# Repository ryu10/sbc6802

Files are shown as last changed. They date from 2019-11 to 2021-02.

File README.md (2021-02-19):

# SBC6802 plus Bus

[Ja](READMEj.md) | En

Rev. 2

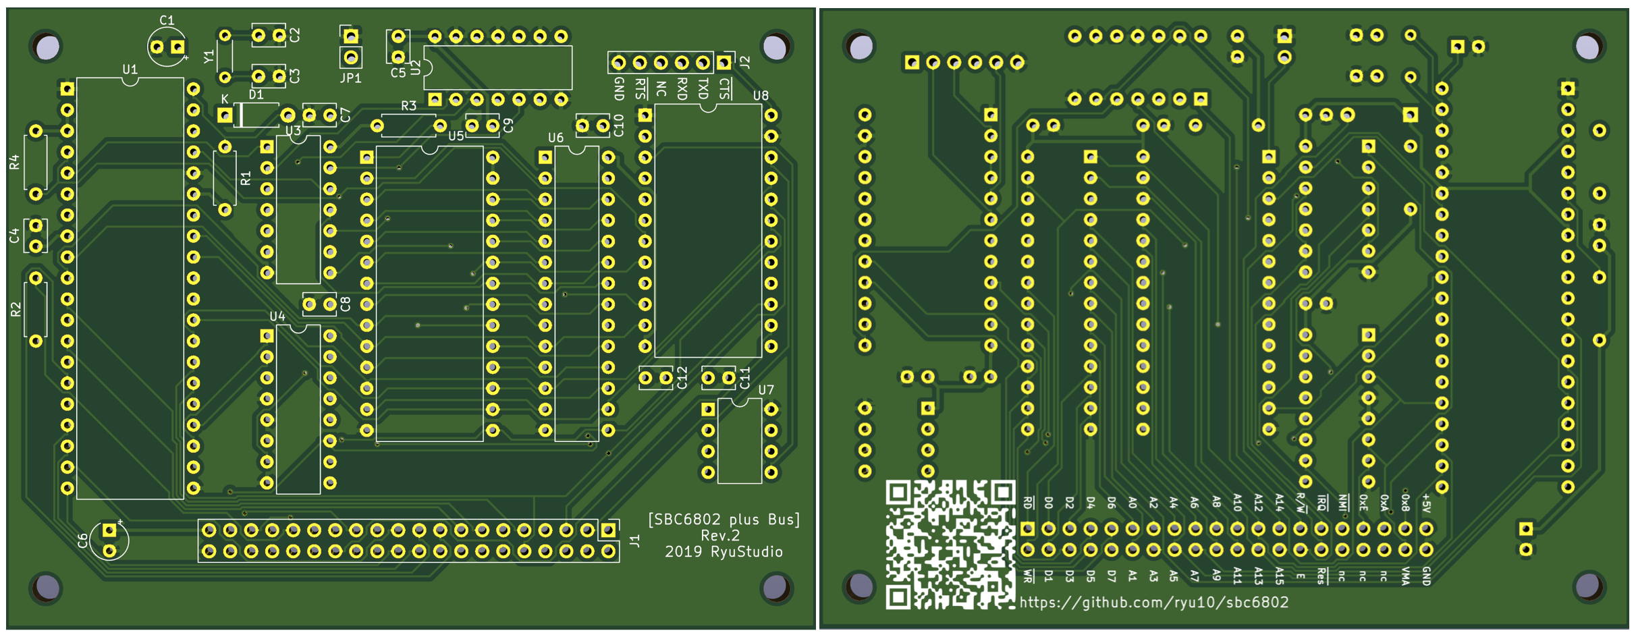
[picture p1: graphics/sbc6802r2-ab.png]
boardr2


An MC6802-based single board computer. The board design is derived from SBC6800 and SBC6809.

## Features

* MC6802 1MHz
* RAM 32KB (0x0000 - 0x7fff)
* ROM 16KB (0xc000 - 0xffff x two banks, selectable using JP1)
* ACIA (0x8018/0x8019)
* SBC-Bus 2.0 Connector

## In This Repository

The following files are included, along with the KiCAD project:

* [Schematic](sbc6802_r2_sch.pdf)
* [Gerber](sbc6802_gerber_r2.zip)
* [BOM](sbc6802_r2_BOM.pdf)

## Programming PIC12F1822

PIC12F1822（U7）can be programmed with ```osc1536.hex``` found in [SBC6800 datapack](http://www.amy.hi-ho.ne.jp/officetetsu/storage/sbc6800_datapack.zip) to generate the clock for 6850 ACIA. The serial port will operate at 9600 bps.
## SBC-Bus

The bus connector J1 supports [SBC-Bus 2.0](https://store.shopping.yahoo.co.jp/orangepicoshop/pico-a-008.html). Pin 38 is routed to 6802 VMA.

If the board is not connected to the SBC-Bus, connect the 5V and GND pins to a +5V regulated power supply.

## Software

Most of the 6800 software found in [SBC6800 datapack](http://www.amy.hi-ho.ne.jp/officetetsu/storage/sbc6800_datapack.zip) are compatible with SBC6802.

## References

* [SBC6800](https://www.switch-science.com/catalog/3581/) / [Technical Data PDF](http://www.amy.hi-ho.ne.jp/officetetsu/storage/en/sbc6800_techdata.pdf)
* [SBC6809](https://www.switch-science.com/catalog/3583/)
* [SBC-Bus 2.0](https://store.shopping.yahoo.co.jp/orangepicoshop/pico-a-008.html)
* [as0 Motorola 6800 Assembler](https://github.com/JimInCA/motorola-6800-assembler)
* [M6800 Assembly VSCode Extension](https://marketplace.visualstudio.com/items?itemName=RyuStudio.m6800-as0)

## License

CC-BY-SA 3.0
2019 ryu10/RyuStudio.

Derived from the original works of SBC6800 and SBC6809 (c) 2017-2018 Tetsuya Suzuki.

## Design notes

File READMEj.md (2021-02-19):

# SBC6802 plus Bus

Ja | [En](README.md)

Rev. 2

boardr2

モトローラ MC68B02 を使用したシングルボードコンピュータです。SBC6800/SBC6809（@vintagechips 様設計）からの派生です。SBC-Bus 2.0（@tomi9tw 様設計）対応のコネクタを装備しています。

## 搭載機能

本ボードの機能は以下の通りです。

* MPU MC6802 1MHz（内蔵 RAM 無効）
* RAM 32KB（0x0000 - 0x7fff）
* ROM 16KB（0xc000 - 0xffff x 2 バンク、ジャンパ JP1 で選択）
* ACIA MC6850（0x8018/0x8019）
* SBC-Bus 2.0 コネクタ

## 主なファイル

リポジトリに含まれる主要なファイルは次の通りです。

* [回路図](sbc6802_r2_sch.pdf)
* [Gerber](sbc6802_gerber_r2.zip)
* [部品表](sbc6802_r2_BOM.pdf)

これ以外に、KiCAD プロジェクトのディレクトリが含まれます。

## PIC12F1822 のプログラミング

PIC12F1822（U7）は 6850 ACIA へシリアルクロックを供給します。[SBC6800 データパック](http://www.amy.hi-ho.ne.jp/officetetsu/storage/sbc6800_datapack.zip)に含まれる osc1536.hex を利用してプログラムすると 9600 bps シリアル通信が可能になります。
## SBC-Bus

SBC-Bus 2.0 の標準ピンアサインから 1 か所変更があります。

* Pin 38: VMA（標準アサインでは NC）

ご利用の SBC-Bus ピンアサインと競合する場合は、基板はんだ面の 38 ピン付近でパターンカットしてください。

SBC6802 plus Bus ボードの電源とリセットボタンは SBC-Bus に依存します。SBC-Bus へ接続しない場合は、ボード下部のコネクタ端子から +5V、GND、Res*（リセット）などを取り出して配線してください。端子名は基板はんだ面のシルクに印刷されています。

## SBC6800 用ソフトウェア

SBC6802 plus Bus のメモリおよび ACIA アドレスは SBC6800 互換です。[SBC6800 データパック](http://www.amy.hi-ho.ne.jp/officetetsu/storage/sbc6800_datapack.zip)に含まれる Mikbug と VTLSA の動作を確認しています。未検証ですがデータパック内の他のソフトウェアも使用可能だと思います。

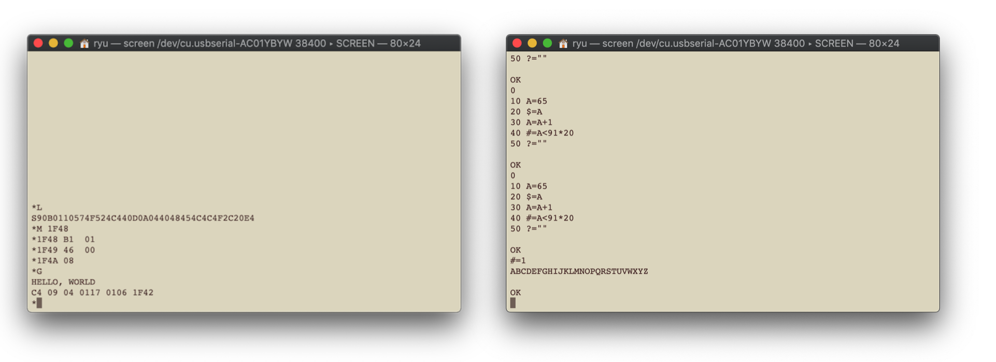
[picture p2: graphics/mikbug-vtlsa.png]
mikbug-vtlsa


## 参考リンク

* [SBC6800](https://www.switch-science.com/catalog/3581/)
* [SBC6809](https://www.switch-science.com/catalog/3583/)
* [SBC-Bus 2.0](https://store.shopping.yahoo.co.jp/orangepicoshop/pico-a-008.html)
* [as0 Motorola 6800 Assembler](https://github.com/JimInCA/motorola-6800-assembler)
* [M6800 Assembly VSCode Extension](https://marketplace.visualstudio.com/items?itemName=RyuStudio.m6800-as0)

## ライセンス

CC-BY-SA 3.0 
2019 ryu10/RyuStudio. 本制作物は以下の設計からの派生です。

SBC6800 and SBC6809, (c) 2017-2018 Tetsuya Suzuki.

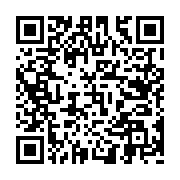
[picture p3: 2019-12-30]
github_sbc6802r2.png

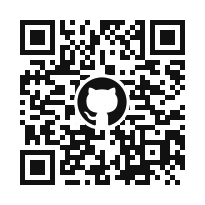
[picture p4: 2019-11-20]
github_sbc6802.png

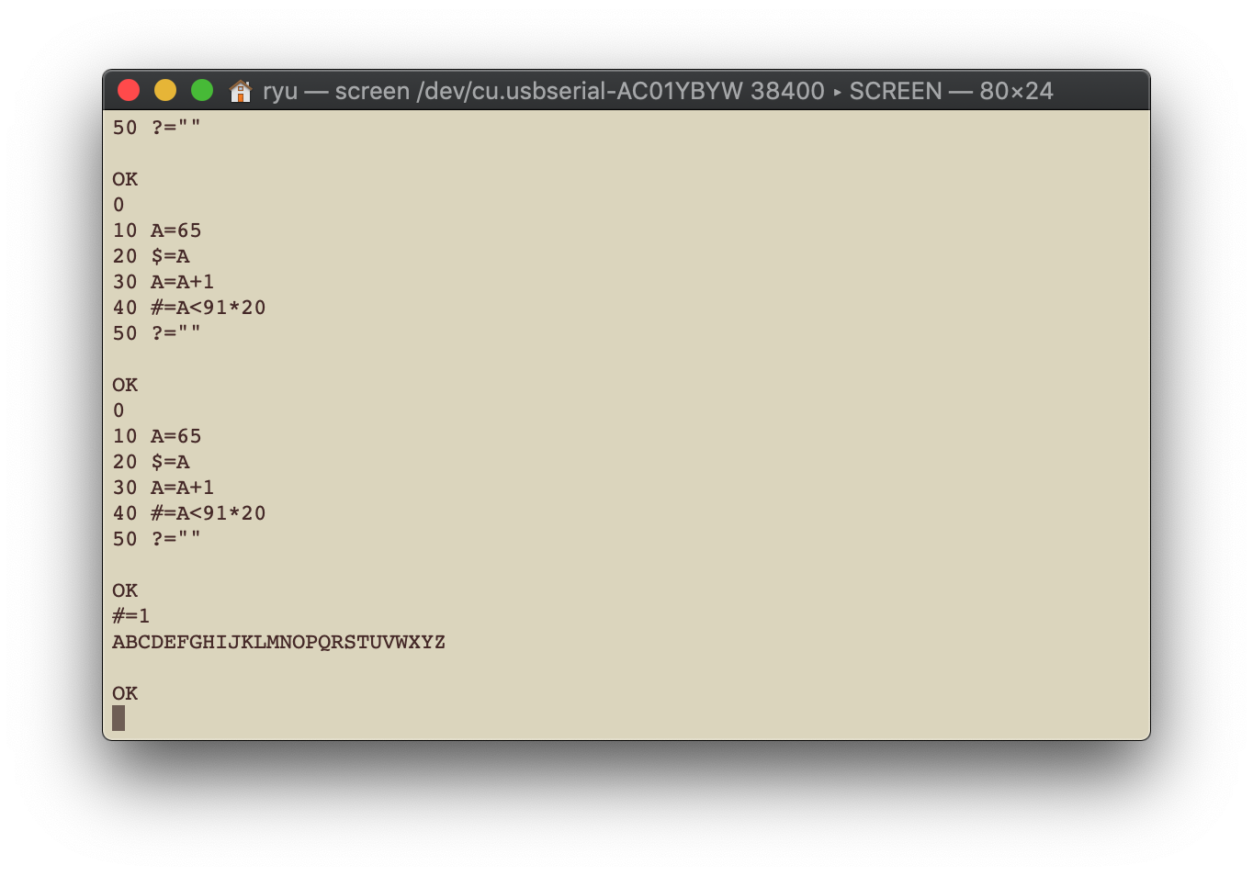
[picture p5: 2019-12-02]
graphics/vtlsa.png

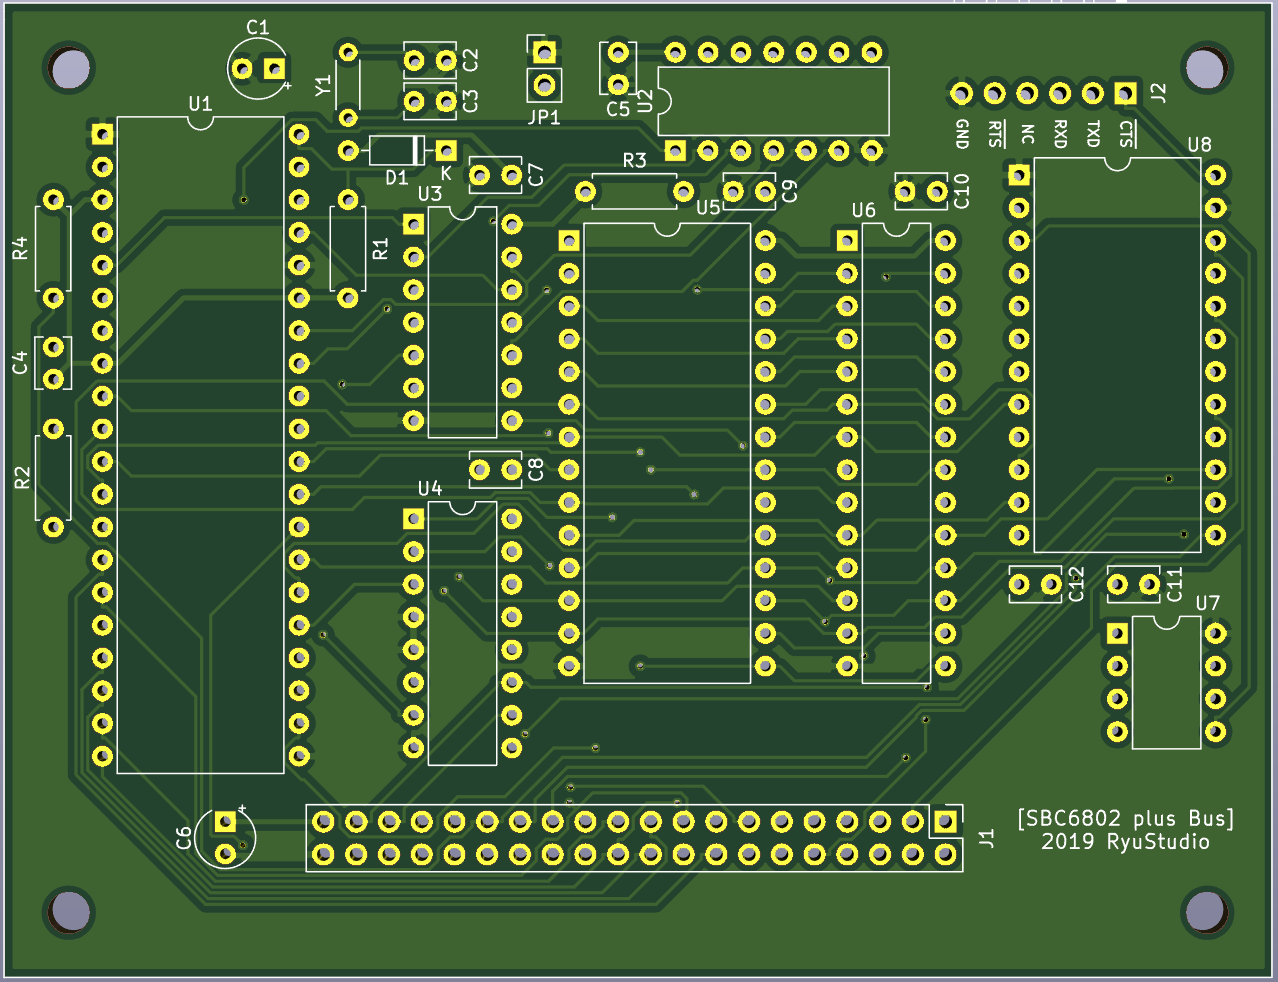
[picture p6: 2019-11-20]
KiCAD/graphics/sbc6802board1a.png

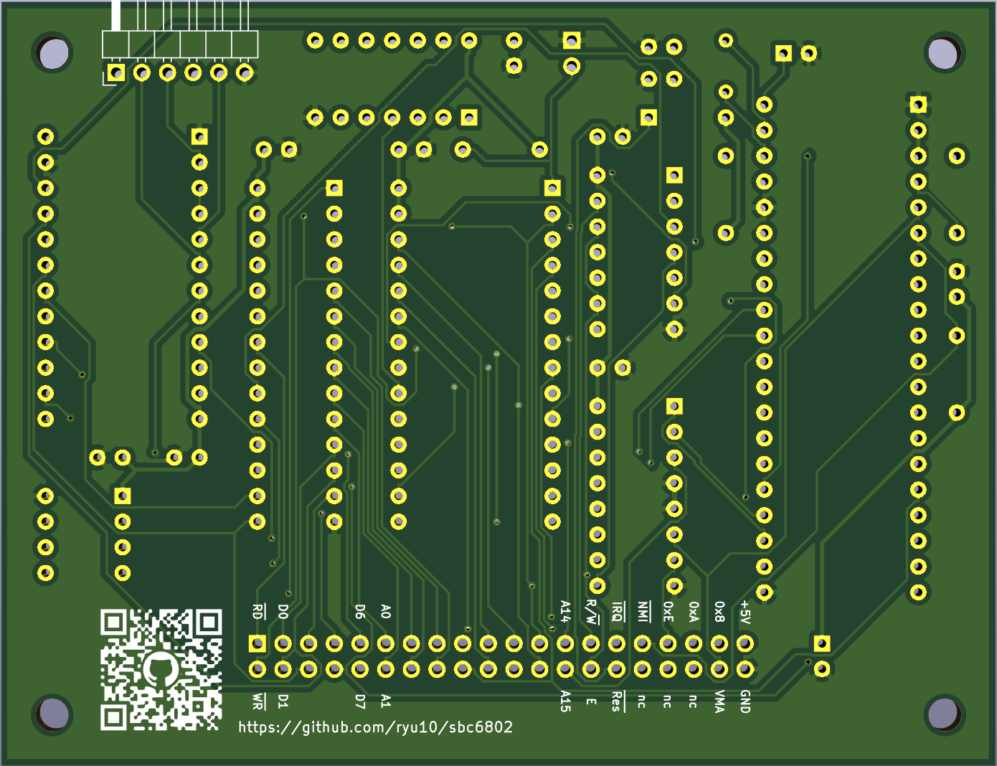
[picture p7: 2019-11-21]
KiCAD/graphics/sbc6802board2a.png

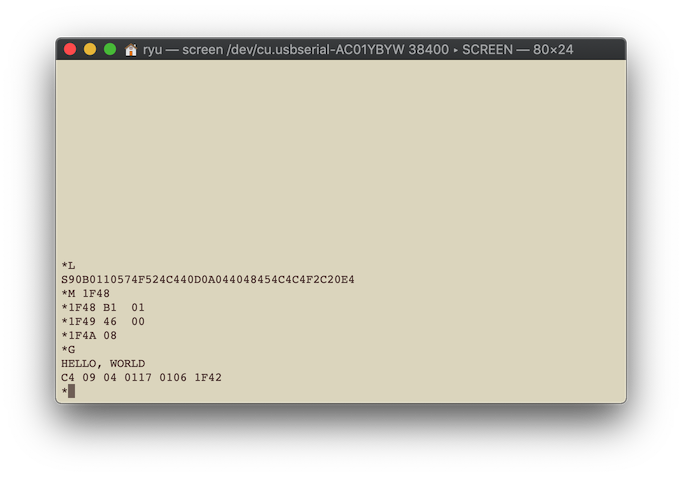
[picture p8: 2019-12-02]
graphics/mikbughello.png

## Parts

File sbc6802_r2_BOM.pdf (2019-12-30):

sbc6802_rev2_BOM

Designator | Package | Quantity | Designation | Supplier and ref
C1 | CP_Radial_Tantal_D4.5mm_P2.50mm | 1 | 10u | electrolytic cap
C11,C10,C12,C4,C5,C7,C8,C9 | C_Disc_D3.8mm_W2.6mm_P2.50mm | 8 | 0.1u | ceramic cap
C2,C3 | C_Disc_D3.8mm_W2.6mm_P2.50mm | 2 | 22p | ceramic cap
C6 | CP_Radial_Tantal_D4.5mm_P2.50mm | 1 | 100u | electrolytic cap
D1 | D_A-405_P7.62mm_Horizontal | 1 | DIODE | diode
G1 | qr_github_sbc6802_r2 | 1 | LOGO | (no parts)
J1 | PinHeader_2x20_P2.54mm_Vertical | 1 | SBC_Bus | https://store.shopping.yahoo.co.jp/soten2/a14061000ux0357.html?sc_i=shp_pc_search_itemlist_shsrg_title
J2 | PinHeader_1x06_P2.54mm_Horizontal | 1 | Conn_01x06 | pin hdr
JP1 | PinHeader_1x02_P2.54mm_Vertical | 1 | Jumper_NO_Small | pin hdr
mh4,mh3,mh2,mh1 | MountingHole_3.2mm_M3 | 4 | M3 | (no parts)
R1 | R_Axial_DIN0207_L6.3mm_D2.5mm_P7.62mm_Horizontal | 1 | 47k | R axial
R2,R3,R4 | R_Axial_DIN0207_L6.3mm_D2.5mm_P7.62mm_Horizontal | 3 | 4.7k | R axial
U1 | DIP-40_W15.24mm | 1 | MC6802 + dip socket | IC
U2 | DIP-14_W7.62mm | 1 | 74LS04 + dip socket | IC
U3 | DIP-14_W7.62mm | 1 | 74LS00 + dip socket | IC
U4 | DIP-16_W7.62mm | 1 | 74LS138 + dip socket | IC
U5 | DIP-28_W15.24mm | 1 | AT28C256 EEPROM + dip socket | https://www.digikey.com/product-detail/en/microchip-technology/AT28C256-15PU/AT28C256-15PU-ND/1008506
U6 | DIP-28_W7.62mm | 1 | 71256 32KB SRAM (w7.62mm) + dip socket
U7 | DIP-8_W7.62mm | 1 | PIC12F1822-IP + dip socket | IC
U8 | DIP-24_W15.24mm | 1 | MC6850 + dip socket | IC
Y1 | R_Axial_DIN0204_L3.6mm_D1.6mm_P5.08mm_Horizontal | 1 | 4MHz | crystal

https://www.digikey.com/product-detail/en/idt-integrated-device-technology-inc/71256SA12TPG/800-3674-ND/2011023

1

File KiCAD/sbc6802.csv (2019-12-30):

Id | Designator | Package | Quantity | Designation | Supplier and ref
1 | logo1 | qr_github_sbc6802_r2 | 1 | LOGO
2 | mh4,mh3,mh2,mh1 | MountingHole_3.2mm_M3 | 4 | M3
3 | J2 | PinHeader_1x06_P2.54mm_Vertical | 1 | Conn_01x06
4 | C1 | CP_Radial_Tantal_D4.5mm_P2.50mm | 1 | 10u
5 | C2,C3 | C_Disc_D3.8mm_W2.6mm_P2.50mm | 2 | 22p
6 | JP1 | PinHeader_1x02_P2.54mm_Vertical | 1 | Jumper_NO_Small
7 | R1 | R_Axial_DIN0207_L6.3mm_D2.5mm_P7.62mm_Horizontal | 1 | 47k
8 | R2,R3,R4 | R_Axial_DIN0207_L6.3mm_D2.5mm_P7.62mm_Horizontal | 3 | 4.7k
9 | J1 | PinHeader_2x20_P2.54mm_Vertical | 1 | Conn_02x20_Odd_Even
10 | U1 | DIP-40_W15.24mm | 1 | MC6802
11 | U2 | DIP-14_W7.62mm | 1 | 74LS04
12 | U3 | DIP-14_W7.62mm | 1 | 74LS00
13 | U4 | DIP-16_W7.62mm | 1 | 74LS138
14 | U5 | DIP-28_W15.24mm | 1 | 28C256 EEPROM
15 | U6 | DIP-28_W7.62mm | 1 | 71256 32KB SRAM
16 | U7 | DIP-8_W7.62mm | 1 | PIC12F1822-IP
17 | U8 | DIP-24_W15.24mm | 1 | MC6850
18 | Y1 | R_Axial_DIN0204_L3.6mm_D1.6mm_P5.08mm_Horizontal | 1 | 4MHz
19 | C11,C10,C12,C4,C5,C7,C8,C9 | C_Disc_D3.8mm_W2.6mm_P2.50mm | 8 | 0.1u
20 | C6 | CP_Radial_Tantal_D4.5mm_P2.50mm | 1 | 100u
21 | D1 | D_A-405_P7.62mm_Horizontal | 1 | D

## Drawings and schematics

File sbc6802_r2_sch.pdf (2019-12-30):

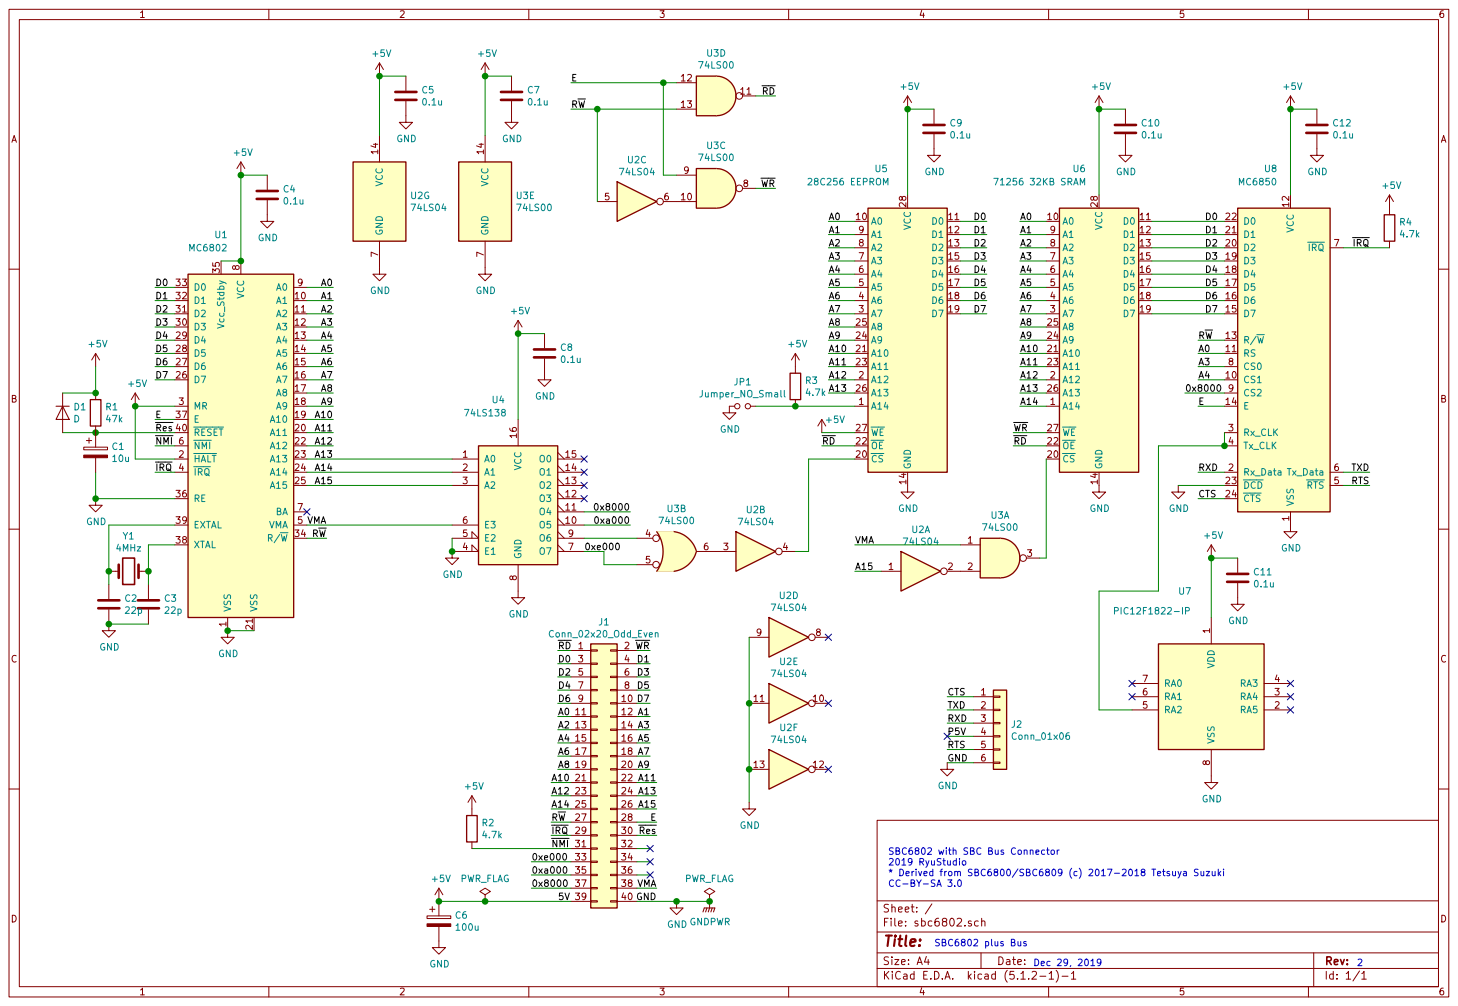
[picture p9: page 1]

1 A1 10 A2 11 A3 12 A4 13 A5 14 A6 15 A7 16 A8 17 A9 18 A10 19 HALT 2 A11 20 VSS 21 A12 22 A13 23 A14 24 A15 25 D7 26 D6 27 D5 28 D4 29 MR 3 D3 30 D2 31 D1 32 D0 33 R/W 34 Vcc_Stdby 35 RE 36 E

Id: 1/1 Title: File: sbc6802.sch Sheet: / SBC6802 plus Bus VSS

* Derived from SBC6800/SBC6809 (c) 2017-2018 Tetsuya Suzuki CC-BY-SA 3.0

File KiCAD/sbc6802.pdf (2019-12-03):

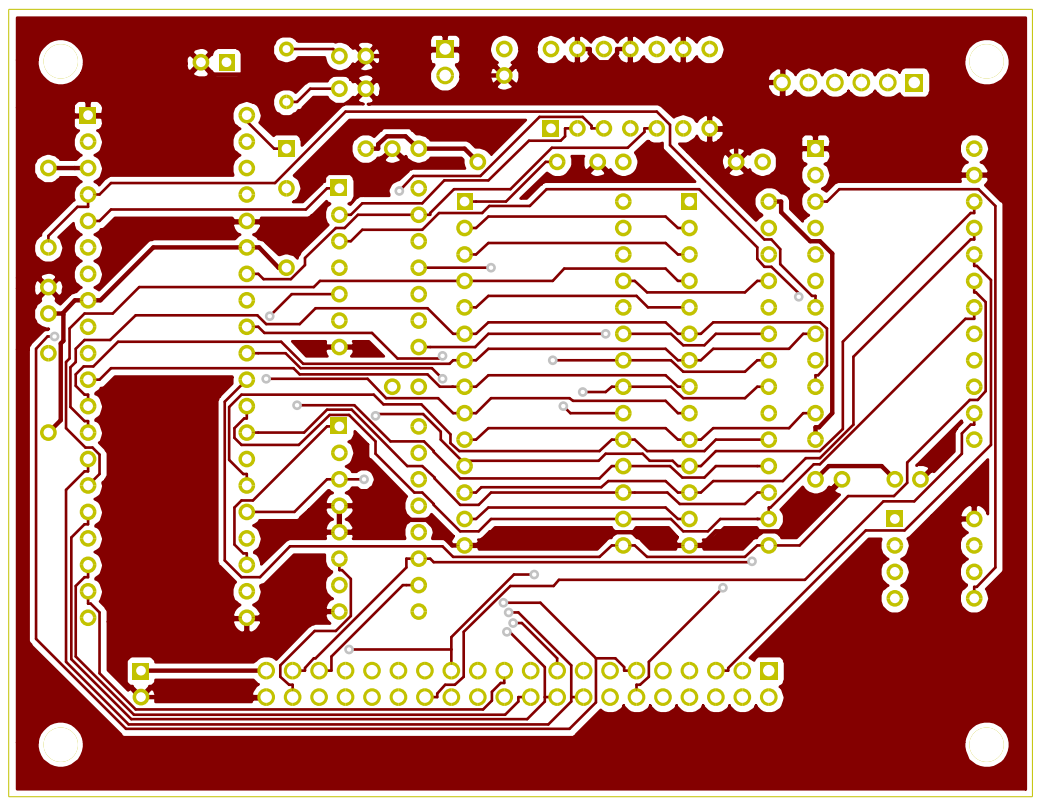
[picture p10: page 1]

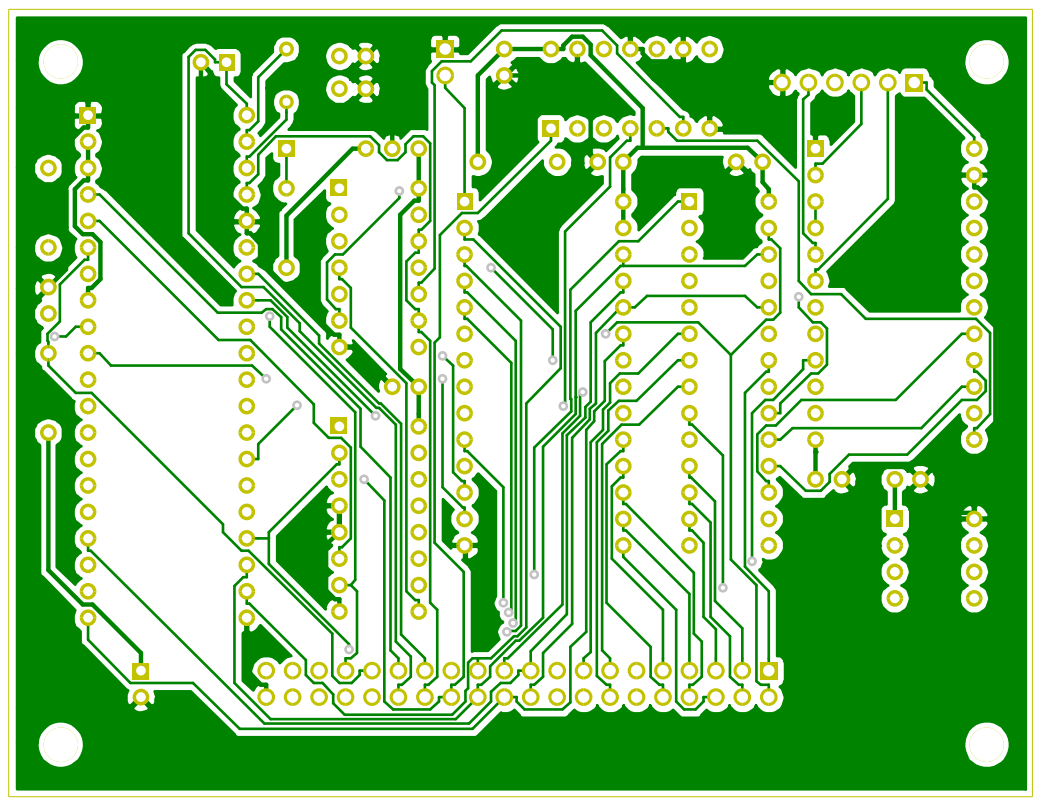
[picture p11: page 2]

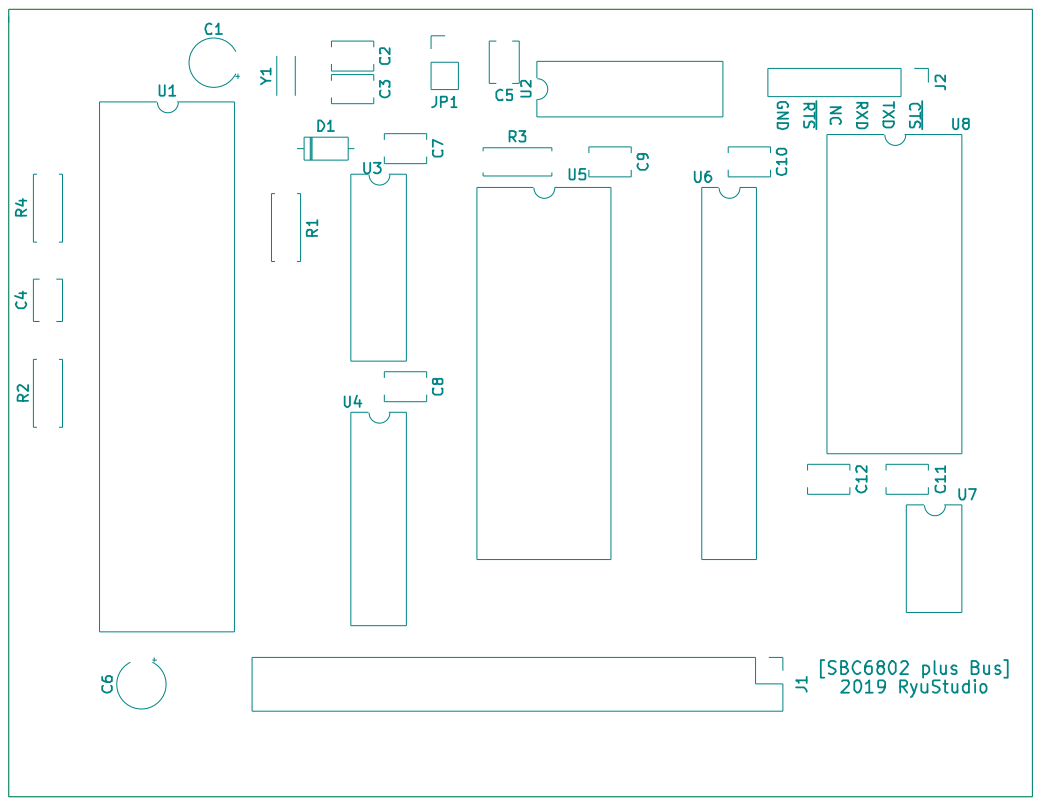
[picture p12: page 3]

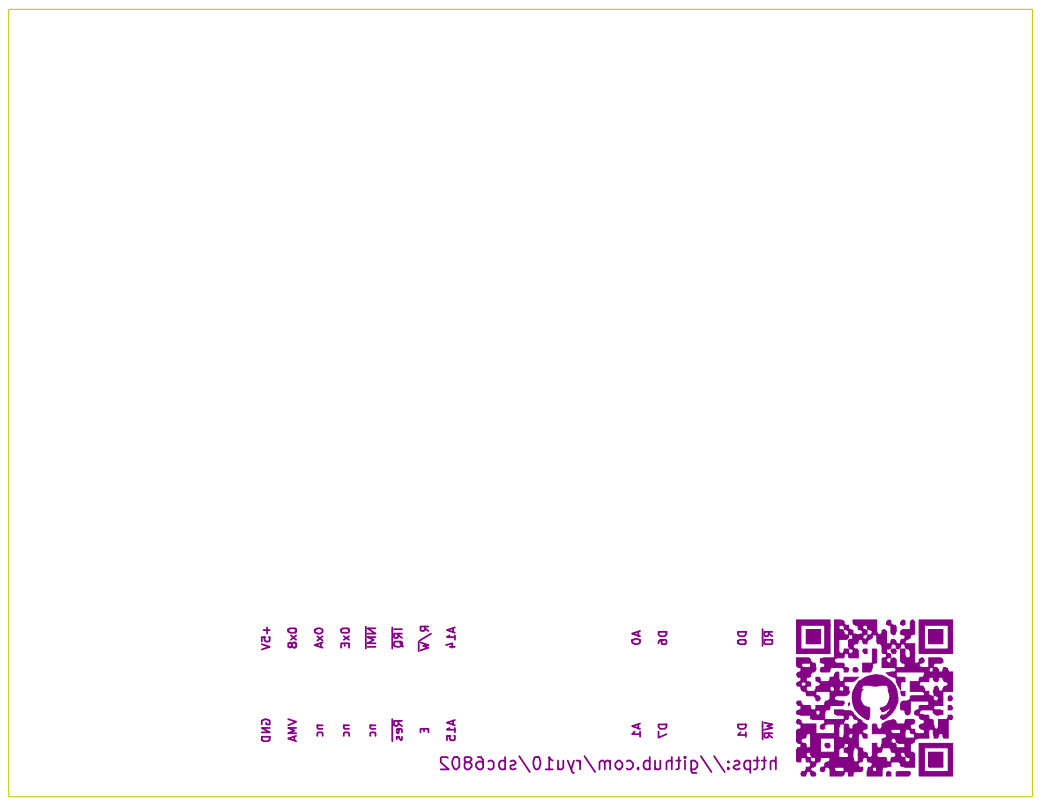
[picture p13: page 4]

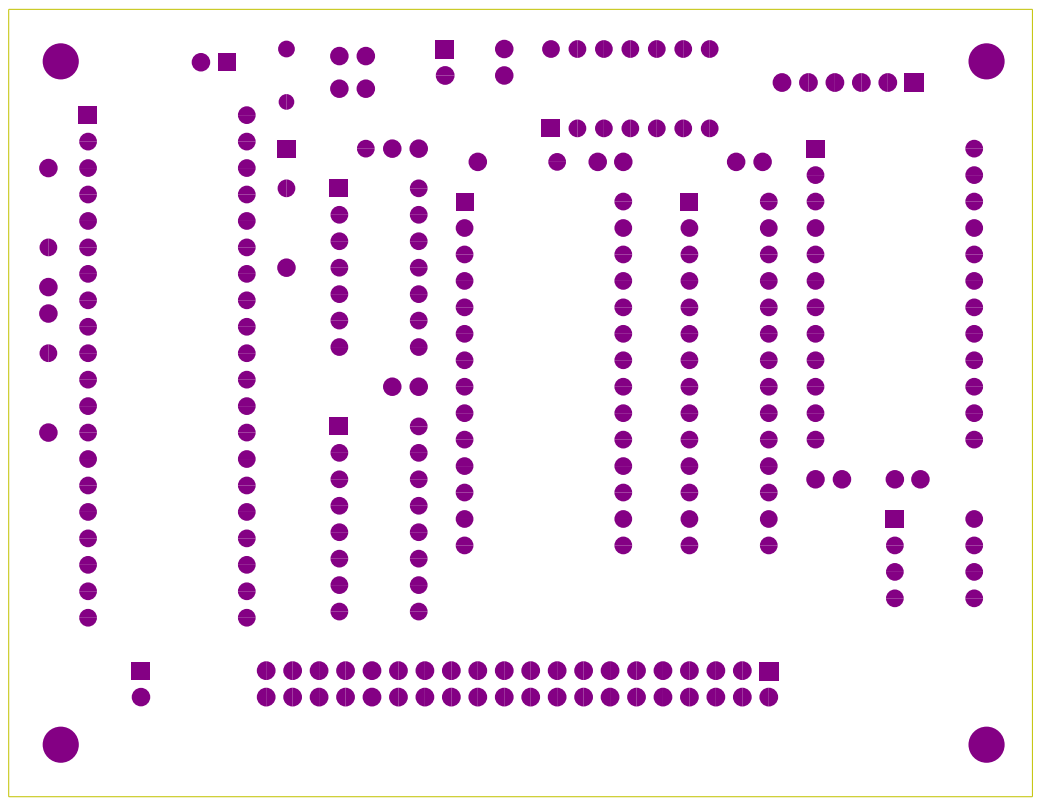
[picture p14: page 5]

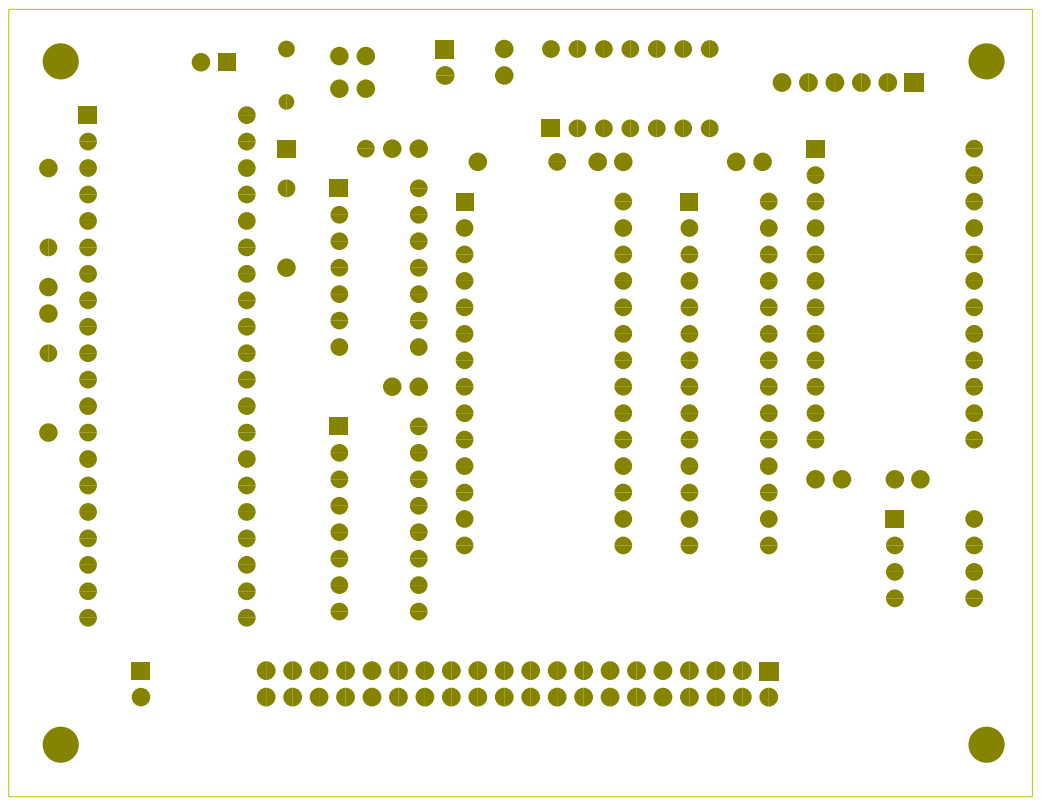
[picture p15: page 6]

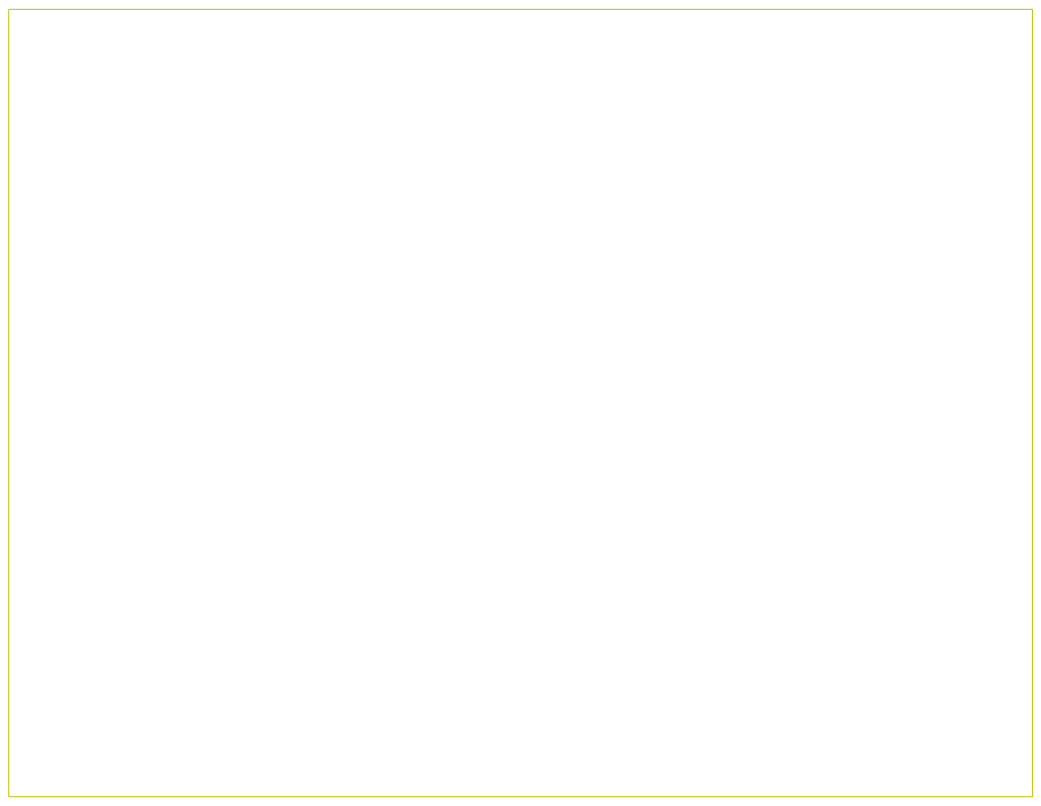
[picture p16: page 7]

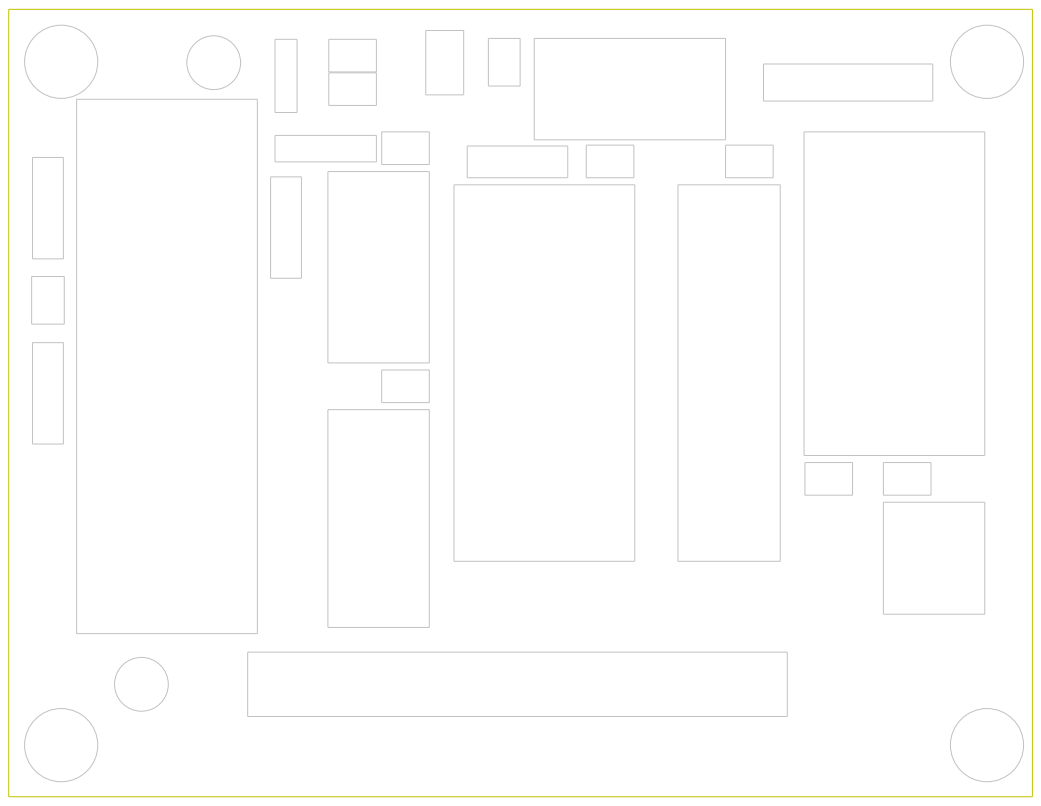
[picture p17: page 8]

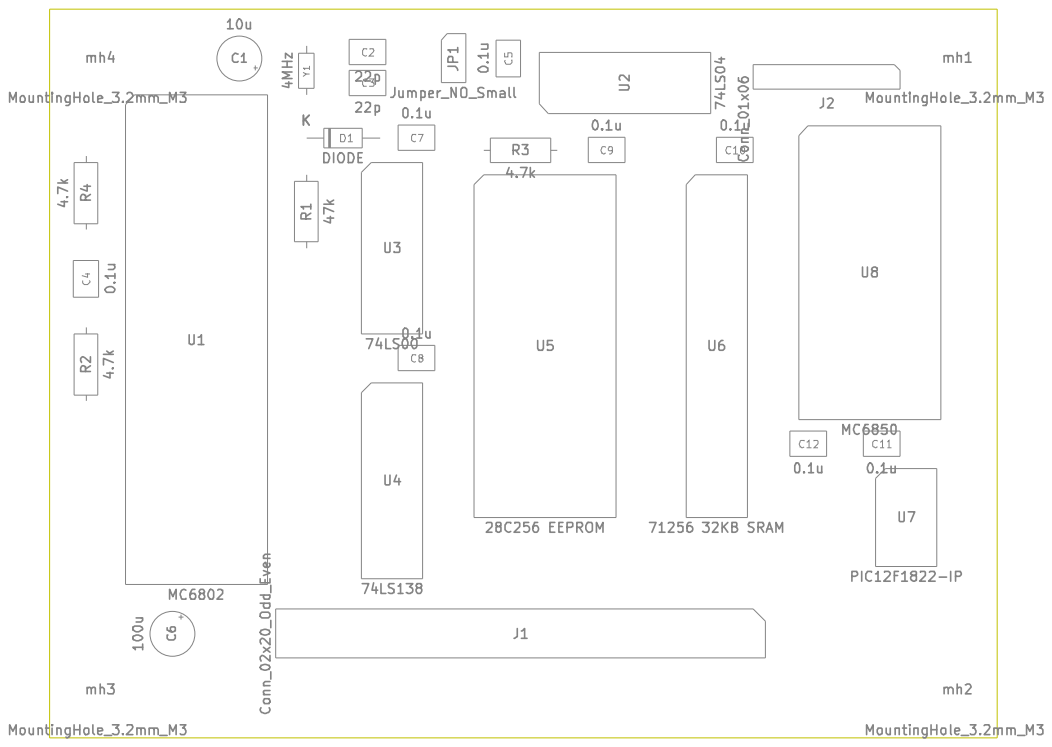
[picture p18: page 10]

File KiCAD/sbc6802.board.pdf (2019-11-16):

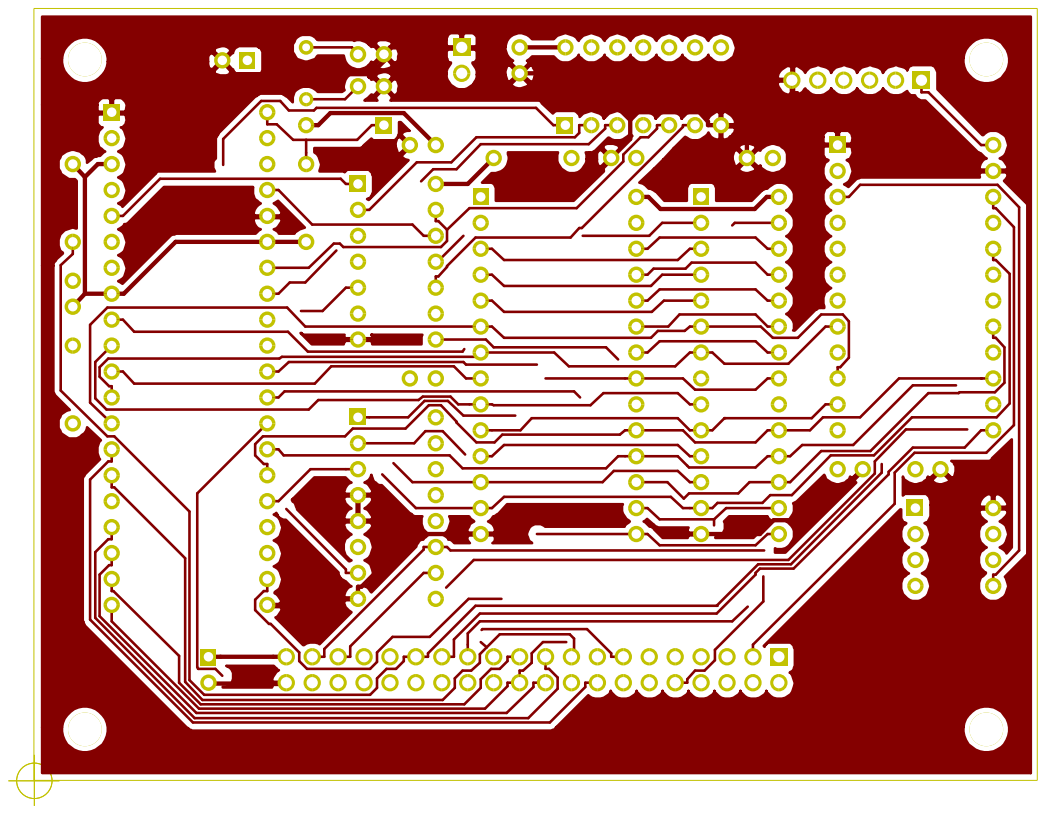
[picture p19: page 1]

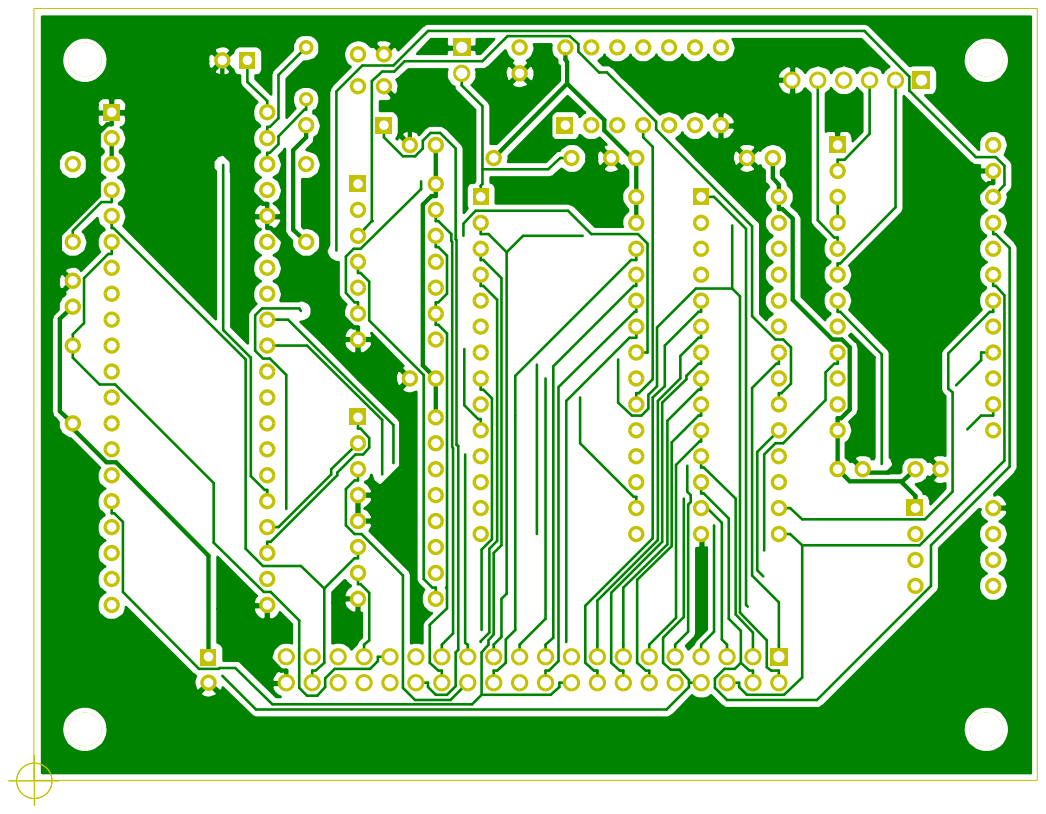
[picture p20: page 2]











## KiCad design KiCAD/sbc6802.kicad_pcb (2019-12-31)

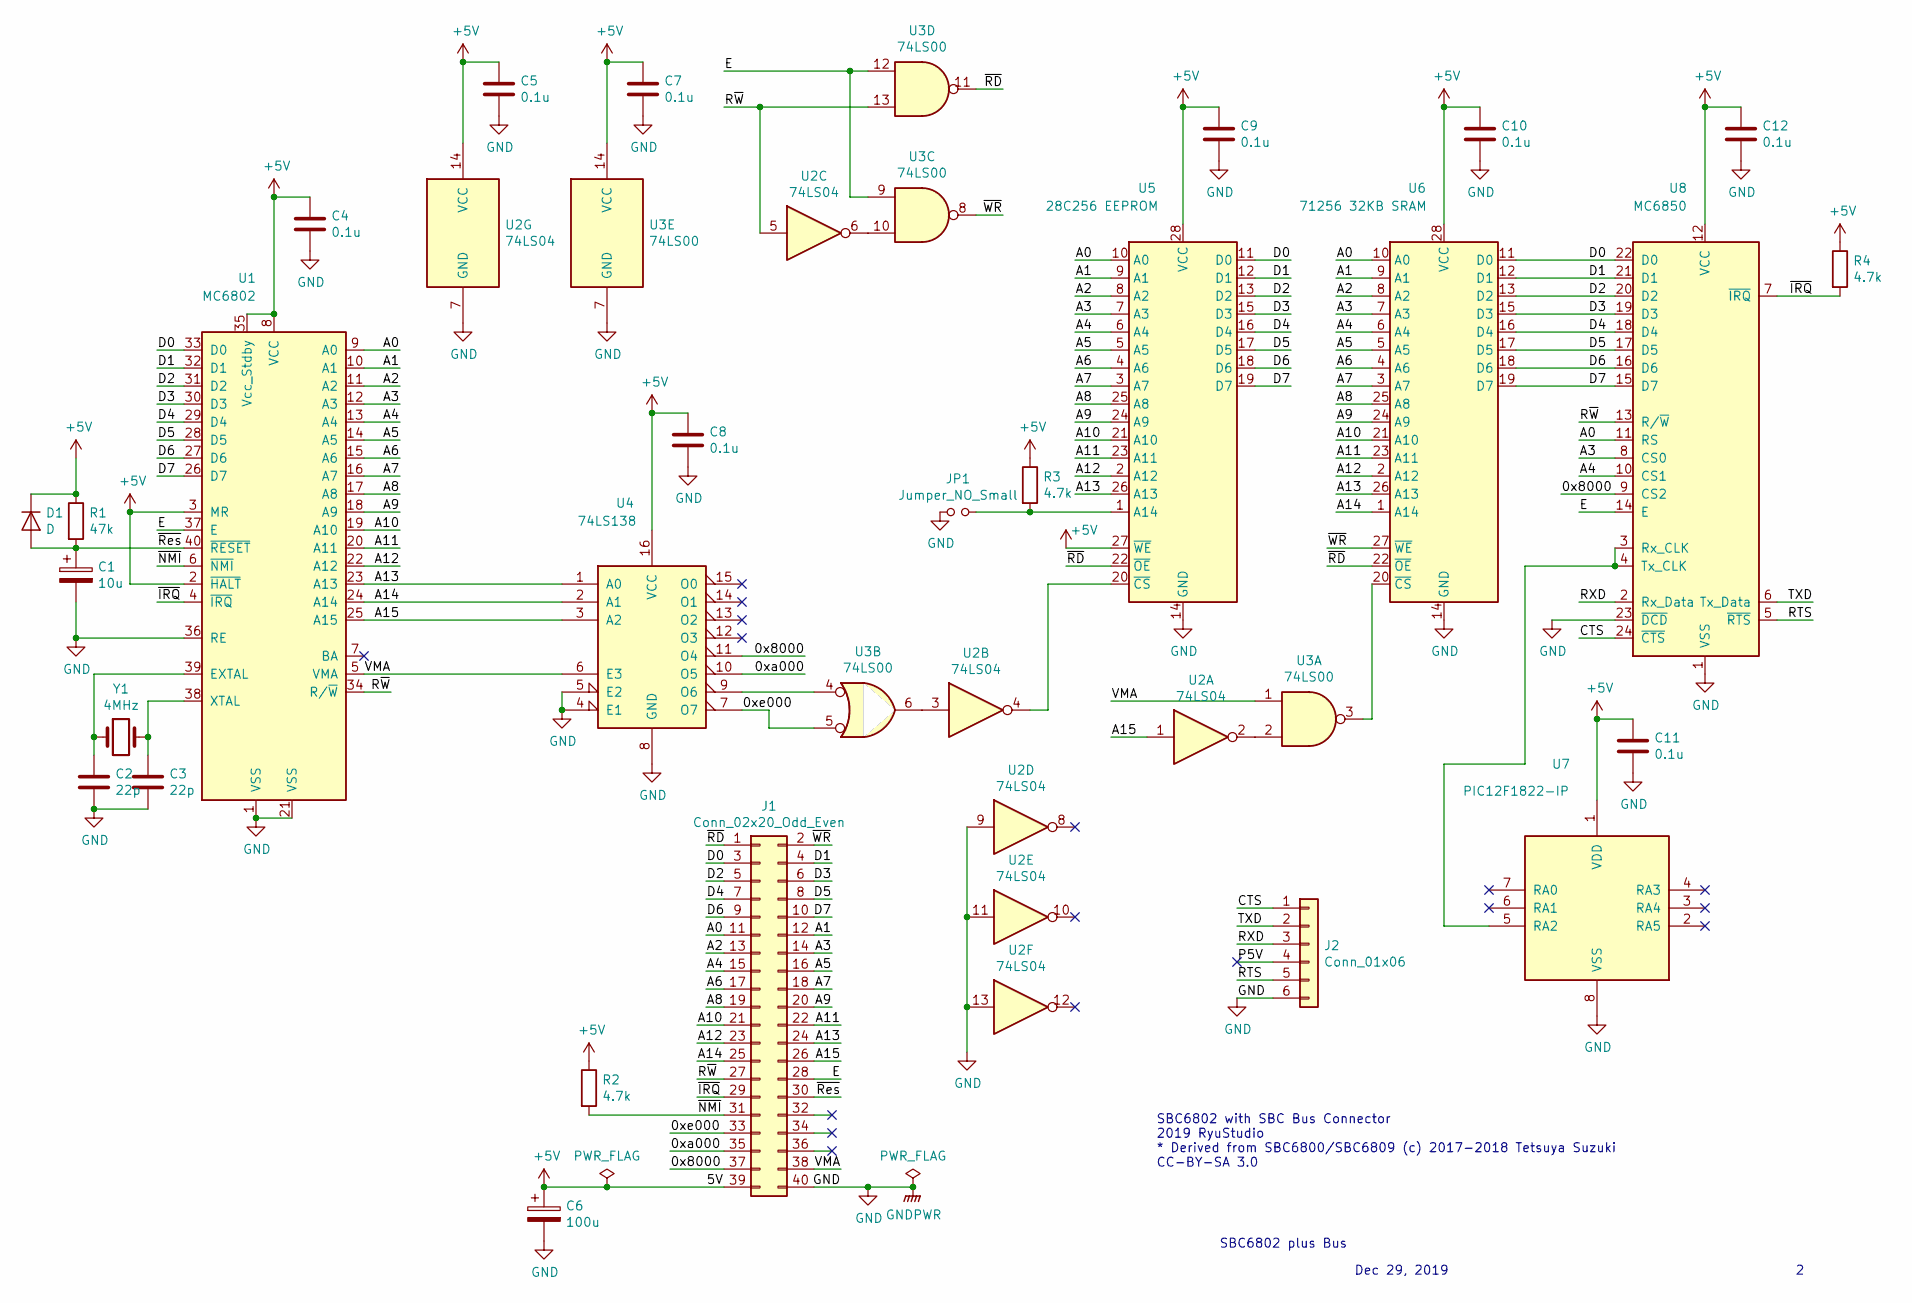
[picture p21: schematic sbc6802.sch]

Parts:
C1: 10u; CP_Radial_Tantal_D4.5mm_P2.50mm
C2, C3: 22p; C_Disc_D3.8mm_W2.6mm_P2.50mm
C4, C5, C7, C8, C9, C10, C11, C12: 0.1u; C_Disc_D3.8mm_W2.6mm_P2.50mm
C6: 100u; CP_Radial_Tantal_D4.5mm_P2.50mm
D1: D; D_A-405_P7.62mm_Horizontal
J1: Conn_02x20_Odd_Even; PinHeader_2x20_P2.54mm_Vertical
J2: Conn_01x06; PinHeader_1x06_P2.54mm_Vertical
JP1: Jumper_NO_Small; PinHeader_1x02_P2.54mm_Vertical
R1: 47k; R_Axial_DIN0207_L6.3mm_D2.5mm_P7.62mm_Horizontal
R2, R3, R4: 4.7k; R_Axial_DIN0207_L6.3mm_D2.5mm_P7.62mm_Horizontal
U1: MC6802; DIP-40_W15.24mm
U2: 74LS04; DIP-14_W7.62mm
U3: 74LS00; DIP-14_W7.62mm
U4: 74LS138; DIP-16_W7.62mm
U5: 28C256 EEPROM; DIP-28_W15.24mm
U6: 71256 32KB SRAM; DIP-28_W7.62mm
U7: PIC12F1822-IP; DIP-8_W7.62mm
U8: MC6850; DIP-24_W15.24mm
Y1: 4MHz; R_Axial_DIN0204_L3.6mm_D1.6mm_P5.08mm_Horizontal

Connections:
+5V: C4.1, C5.1, C6.1, C7.1, C8.1, C9.1, C10.1, C11.1, C12.1, D1.1 (K), J1.39, R1.1, R2.1, R3.1, R4.1, U1.2 (~HALT), U1.3 (MR), U1.8 (VCC), U1.35 (Vcc_Stdby), U2.14 (VCC), U3.14 (VCC), U4.16 (VCC), U5.27 (~WE), U5.28 (VCC), U6.28 (VCC), U7.1 (VDD), U8.12 (VCC)
/0x8000: J1.37, U4.11 (O4), U8.9 (CS2)
/0xa000: J1.35, U4.10 (O5)
/0xe000: J1.33, U3.5, U4.7 (O7)
/A0: J1.11, U1.9 (A0), U5.10 (A0), U6.10 (A0), U8.11 (RS)
/A1: J1.12, U1.10 (A1), U5.9 (A1), U6.9 (A1)
/A2: J1.13, U1.11 (A2), U5.8 (A2), U6.8 (A2)
/A3: J1.14, U1.12 (A3), U5.7 (A3), U6.7 (A3), U8.8 (CS0)
/A4: J1.15, U1.13 (A4), U5.6 (A4), U6.6 (A4), U8.10 (CS1)
/A5: J1.16, U1.14 (A5), U5.5 (A5), U6.5 (A5)
/A6: J1.17, U1.15 (A6), U5.4 (A6), U6.4 (A6)
/A7: J1.18, U1.16 (A7), U5.3 (A7), U6.3 (A7)
/A8: J1.19, U1.17 (A8), U5.25 (A8), U6.25 (A8)
/A9: J1.20, U1.18 (A9), U5.24 (A9), U6.24 (A9)
/A10: J1.21, U1.19 (A10), U5.21 (A10), U6.21 (A10)
/A11: J1.22, U1.20 (A11), U5.23 (A11), U6.23 (A11)
/A12: J1.23, U1.22 (A12), U5.2 (A12), U6.2 (A12)
/A13: J1.24, U1.23 (A13), U4.1 (A0), U5.26 (A13), U6.26 (A13)
/A14: J1.25, U1.24 (A14), U4.2 (A1), U6.1 (A14)
/A15: J1.26, U1.25 (A15), U2.1, U4.3 (A2)
/CTS: J2.1, U8.24 (~CTS)
/D0: J1.3, U1.33 (D0), U5.11 (D0), U6.11 (D0), U8.22 (D0)
/D1: J1.4, U1.32 (D1), U5.12 (D1), U6.12 (D1), U8.21 (D1)
/D2: J1.5, U1.31 (D2), U5.13 (D2), U6.13 (D2), U8.20 (D2)
/D3: J1.6, U1.30 (D3), U5.15 (D3), U6.15 (D3), U8.19 (D3)
/D4: J1.7, U1.29 (D4), U5.16 (D4), U6.16 (D4), U8.18 (D4)
/D5: J1.8, U1.28 (D5), U5.17 (D5), U6.17 (D5), U8.17 (D5)
/D6: J1.9, U1.27 (D6), U5.18 (D6), U6.18 (D6), U8.16 (D6)
/D7: J1.10, U1.26 (D7), U5.19 (D7), U6.19 (D7), U8.15 (D7)
/E: J1.28, U1.37 (E), U3.9, U3.12, U8.14 (E)
/RTS: J2.5, U8.5 (~RTS)
/RXD: J2.3, U8.2 (Rx_Data)
/R~W: J1.27, U1.34 (R/~W), U2.5, U3.13, U8.13 (R/~W)
/TXD: J2.2, U8.6 (Tx_Data)
/VMA: J1.38, U1.5 (VMA), U3.1, U4.6 (E3)
/~IRQ: J1.29, R4.2, U1.4 (~IRQ), U8.7 (~IRQ)
/~NMI: J1.31, R2.2, U1.6 (~NMI)
/~RD: J1.1, U3.11, U5.22 (~OE), U6.22 (~OE)
/~Res: C1.1, D1.2 (A), J1.30, R1.2, U1.40 (~RESET)
/~WR: J1.2, U3.8, U6.27 (~WE)
GND: C1.2, C2.2, C3.2, C4.2, C5.2, C6.2, C7.2, C8.2, C9.2, C10.2, C11.2, C12.2, J1.40, J2.6, JP1.1, U1.1 (VSS), U1.21 (VSS), U1.36 (RE), U2.7 (GND), U2.9, U2.11, U2.13, U3.7 (GND), U4.4 (E1), U4.5 (E2), U4.8 (GND), U5.14 (GND), U6.14 (GND), U7.8 (VSS), U8.1 (VSS), U8.23 (~DCD)
unnamed: C2.1, U1.39 (EXTAL), Y1.1
unnamed: C3.1, U1.38 (XTAL), Y1.2
unnamed: JP1.2, R3.2, U5.1 (A14)
unnamed: U2.2, U3.2
unnamed: U2.3, U3.6
unnamed: U2.4, U5.20 (~CS)
unnamed: U2.6, U3.10
unnamed: U3.3, U6.20 (~CS)
unnamed: U3.4, U4.9 (O6)
unnamed: U7.5 (RA2), U8.3 (Rx_CLK), U8.4 (Tx_CLK)

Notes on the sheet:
SBC6802 plus Bus
Dec 29, 2019
SBC6802 with SBC Bus Connector 2019 RyuStudio * Derived from SBC6800/SBC6809 (c) 2017-2018 Tetsuya Suzuki CC-BY-SA 3.0

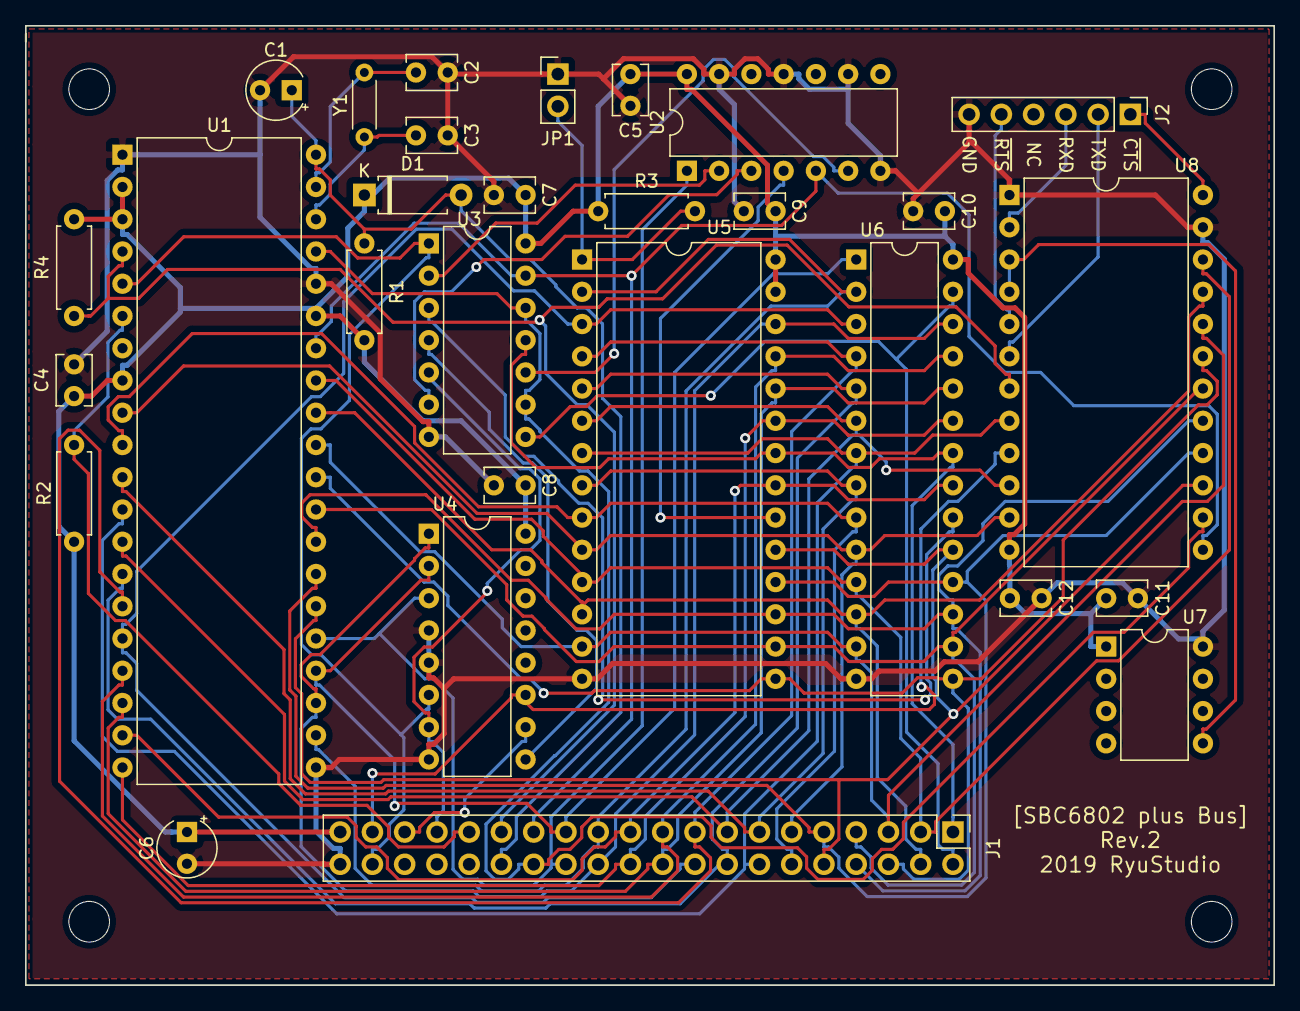
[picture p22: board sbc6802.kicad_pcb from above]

Board: 2 copper layers, 98.3 x 75.6 mm, 34 parts (1 on the bottom side), 51 nets.

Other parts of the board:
logo1: LOGO; qr_github_sbc6802_r2
mh1, mh2, mh3, mh4: M3; MountingHole_3.2mm_M3

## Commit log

2019-11-30 kicad dir
    [sbc6802.dsn, sbc6802.kicad_pcb, sbc6802.sch]
2019-12-02 init rev2
    [sbc6802.dsn, sbc6802.kicad_pcb, sbc6802.sch]
2019-12-03 rev2 pcb & readme
    [sbc6802-B_Cu.gbl, sbc6802-B_Mask.gbs, sbc6802-B_Paste.gbp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]
2019-12-30 rev2 kicad/gerber
    [sbc6802-B_Cu.gbl, sbc6802-B_Mask.gbs, sbc6802-B_SilkS.gbo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]
2019-12-31 rev2 gerber
    [sbc6802-B_Cu.gbl, sbc6802-B_Mask.gbs, sbc6802-B_Paste.gbp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]
2019-12-31 rev2 readme
    [sbc6802-B_Cu.gbl, sbc6802-B_Mask.gbs, sbc6802-B_Paste.gbp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]
